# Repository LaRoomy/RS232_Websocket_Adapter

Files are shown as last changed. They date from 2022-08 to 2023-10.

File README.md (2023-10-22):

# RS232_Websocket_Adapter



This Project could be considered as the next-level development after my accomplishments with the apps for the serial data transmission to/from older EPL2 based machines. There were a few points which bothered me on my recent solutions: First thing is that the computer has to come to the machine, means there hast to be a (short) cable connection. What if I want to send data from the office? Second thing is the limitation to the windows platform. What if I want to use a mac or an android/ios-tablet or something. So this project accomplishes the following:
- Enable data exchange over RS232 interface (especially for EPL2 based machines)
- Exchange this data over a wireless connection in the local network
- Provides a platform independent front-end which can be accessed via browser

This repository provides all necessary data to build the WebSocket-Adapter.
- CAD data to create the [printed circuit board](CAD/Board)
- CAD data to create the [case](CAD/Case) for the adapter with a 3D printer
- The source code for the [backend/frontend](RS232WebSocketAdapter)

The front-end is accessible via browser from every device in the local network over the url "ncinterface.local".

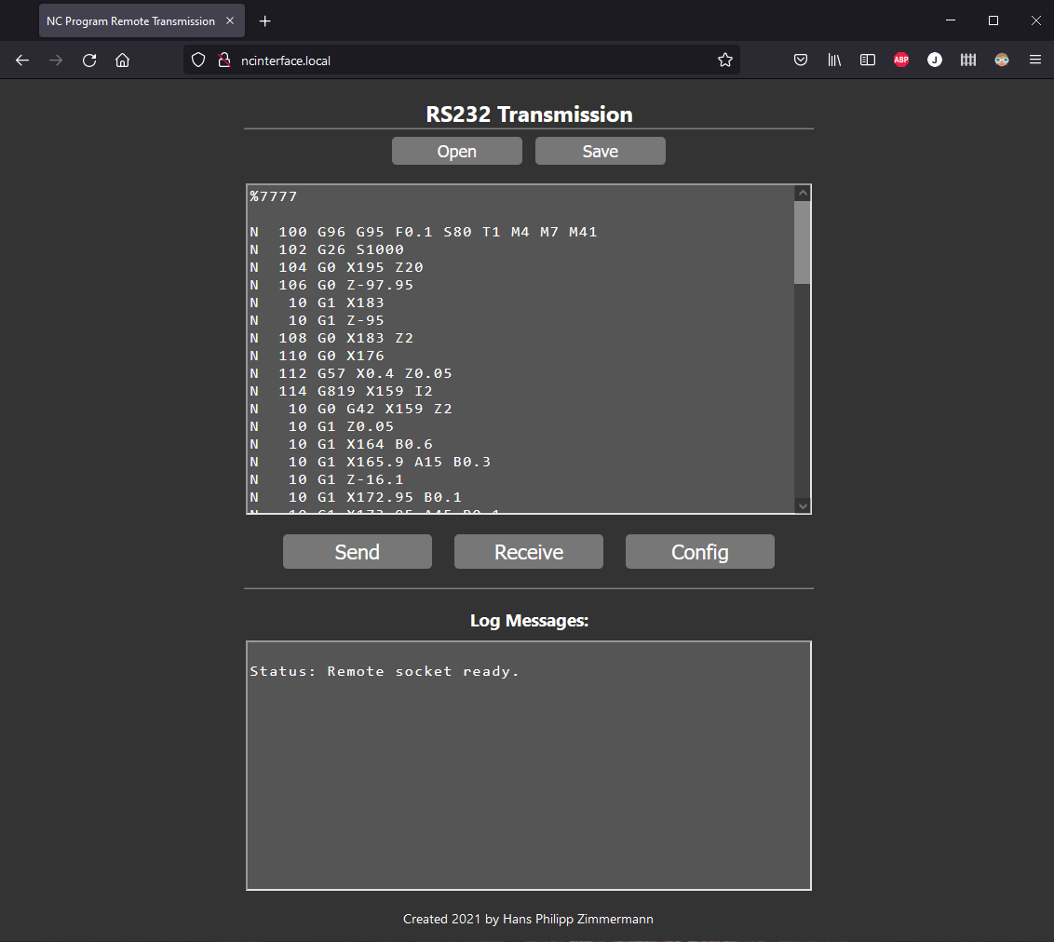
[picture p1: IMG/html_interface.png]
front-end view


### Special capabilities of the adapter
- The board contains a switch to select the RX/TX mode. The two lines can be crossed by this switch or used in line.
- The board also has pinheader bars. The level of these bars can be set directly out of the program and indiviually set for each of the hardware-handshake pins of the RS232 interface. This ensures the possibility to make the interface conform to every handshake needs of the machine.

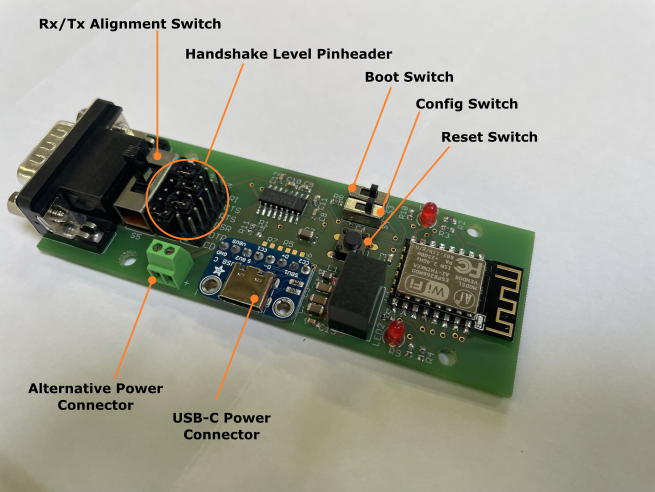
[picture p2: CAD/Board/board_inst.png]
board specifications


**NOTE:** _In this picture the config-switch is in the **normal execution** position and the boot-switch is in **program mode** position_

### How it works

The adapter logs in to the local network and advertises its local domain *ncinterface.local* via MDNS. It acts as an webserver. By entering the url *ncinterface.local* the interface website is loaded and remains connected by a websocket. The interface consists of the transmission page and the config page. The RS232 connection parameter can be set using the config page.

### How to configure the network

To set up the network credentials the serial connection of the adapter must be used. Connect the adapter to a pc via USB to Serial adapter. Make sure all jumper of the handshake-pinheader bars are removed. Otherwise it will not work properly. The config switch of the adapter must be set to the appropriate position. Now connect the power-source and the device will start in config mode. To configure the network every serial terminal program can be used. I recommend to use my free app [*EPL Exchange*](https://epl-exchange.blogspot.com/). The parameters of the config interface are:
- Baudrate: 9600
- Parity: None
- Databits: 8
- Stopbits: 1
- Handshake: None

To set up the SSID (network name): type in "ssid", to set up the password for the network: type in "password" and follow the prompt respectively. Typing in "?" shows instructions to use. To check if the connection works, put the config switch in the *normal execution* position and press reset. While trying to connect the red led blicks. If the device is connected to the network the blue led is on.

### How to get it ready to use

In many modern scenarios the handshake is ignored, known as RS232 3-wire interface, but machines running EPL2 needs specific levels on specific hardware handshake pins during transmission and some other pins must be set to GND. The following configuration worked for all machines I have to do with:

| Pin Name | Configuration |
| --- | --- |
| RI | GND |
| CTS | GND |
| RTS | OUT |
| DSR | Not connected |
| DTR | OUT |
| CD | GND |

When the jumper bridges on the pinheaders are connected. Make sure the config-switch is in *normal execution* position and the boot-switch is in *program mode* position. Set the Rx/Tx switch in the appropriate position and connect the adapter with the machine. Plug the power source in. If all is correct configured, the adapter shows the blue led indicating the successful connection with the network.

Now every device in the local network is able to access the adapters interface by opening the url **ncinterface.local**

#### Note:
- There are some problems with browsers. I recommend firefox, this works on all platforms. The known problems are:
   - Microsoft Edge does not support opening *.local* urls. Instead a internet search is being performed. The solution here is to add the url as a bookmark. Clicking this bookmark opens the interface.
   - On iOS, Safari has problems with the websocket because the app using this interface must have permission granted to use the local network. Safari does not  seem to have this capability at all, so it won't work. Other browsers on iOS, like firefox, are working. By opening the interface a dialog to request the permission to use the local network is displayed. This must be positive confirmed.
- The interface configuration which can be done on the config page is only for the transmission mode (when sending data via WLAN), **NOT** for the configuration interface of the adapter. The configuration interface parameter are always the same (printed earlier in this readme).

### Resources
- Printed Circuit Board resources can be found [here](CAD/Board)
- CAD files for the case are located [here](CAD/Case)
- The source-code for controller is [here](RS232WebSocketAdapter)
- A website with further information on the [EPL2 data-transmission](https://epl2-datatransmission.blogspot.com/2020/08/epl2-datenubertragung.html)
- Infos about the application [EPL-Exchange](https://epl-exchange.blogspot.com/) which could be used to configure the adapter

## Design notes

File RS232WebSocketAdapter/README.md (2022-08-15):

## RS232 WebSocket-Adapter Firmware project

This is the firmware for the WebSocket-Adapter.
- MCU: Espressif ESP8266
- Development Platform: [PlatformIO](https://platformio.org/)
- Framework: Arduino
- IDE: [Microsoft Visual Studio Code](https://platformio.org/platformio-ide)

---

### How to build
- Download [Visual Studio Code](https://platformio.org/platformio-ide)
- Install the PlatformIO IDE Extension
- Extensions for code management are also necessary. We need support for C/C++ and html/css/javascript
- Clone this Repository to your local machine
- Open the sub-folder *RS232WebSocketAdapter* of the Repository in VSCode. Or use the PlatformIO Extension and select *Open Project*. Anyway the opened folder must contain the *platformio.ini* file
- Click on the PlatformIO icon on the left pane to open the project tasks.
- Make sure to enter the boot mode of the device by switching the boot switch in the *boot mode* position and then press reset to enter boot mode
- Select *Build Filesystem Image* and when finished select *Upload Filesystem Image*
- Open the *root.h* file in the editor.

Here are two defines:
```C++
// if set, this enables some functions which are only intended for testing purposes
#define     EVALUATION_MODE

// if set, this initializes the eeprom persistent data, only intended for initial startup of the device
#define     INITIAL_MODE 
```
If the evaluation-mode define is set, the device outputs log messages on the serial interface. This is helpful while developing, but is not allowed if the device is used as intended since the serial interface is used to transmit data to the rs232 endpoint.

When first uploading the firmware to the device, the initial-mode define should be set to init the (pseudo)eeprom data segment with valid values. Otherwise the config parameter are loaded with invalid values. But if this is done, the define must be commented out and the firmware must be overridden with the new binary.

- Select *Build* in the project tasks list on the left
- When finished, select *Upload*
- If this was the first build, put the boot switch in *program mode* position and press reset. When the program was executed once on the device, put the device back in boot mode. Disable the initial-mode define value and click *Build* and *Upload* again.

### Sequence of the program
- On startup the device checks the configuration switch
- If it is set, the device enteres the configuration mode and the network credentials can be configured via serial interface
- Otherwise the device tries to connect to saved ssid/password combination
- If the connection succeeded, the device enteres data transmission mode and the interface can be accessed via *ncinterface.local* inside of the local network
- If the connection fails, the device enters the configuration mode

### Source Files
The MCU data consists of two elements: the firmware and the filesystem-image.

The filesystem image is used to store the files for the WebServer (html, css, js):
- **webSocket_nc_Transmission.html**  (front-end code for the transmission page of the interface)
- **webSocket_nc_Configuration.html**  (front-end code for the configuration page of the interface)
- **exStyles.css**  (provides the styles for the html pages)
- **exec_script.js**  (implements the back-end websocket functionality, and page behavior)

The C++ source files are used to generate the binary for the MCU:
- **root.h / root.cpp**  (implements the main functionality)
- **serial.h / serial.cpp**  (implements the serial interface communication)
- **stringtable.h**  (provides the strings for the user-interface)
- **main.cpp**  (entry-point of the WebSocket-Adapter firmware):

```C++
#include "root.h"

// create root instance
RootComponent rootC;

// valid access to root instance from all locations
RootComponent* getRootClass(){
  return &rootC;
}

void setup(){
  // initialize component
  rootC.init();
}

void loop(){
  // run
  rootC.onLoop();
}
```
As you can see, the whole functionality is coverd by the instance of the RootComponent object.

---

### Note:
With the pinheaders on the board it is possible to set each hardware handshake pin to a specific level (HIGH/LOW). Place a jumper bridge either to the GND pinheader or to the OUT pinheader. The OUT pinheader can be controlled from the firmware to customize the levels of the pin on a specific operation.

**But when programming or configuring the device, all jumper must be removed to ensure a reliable operation.**

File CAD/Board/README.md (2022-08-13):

## RS232 WebSocket-Adapter Board

This is the CAD data section for the printed circuit board. The board file is production-ready.

Schematic:

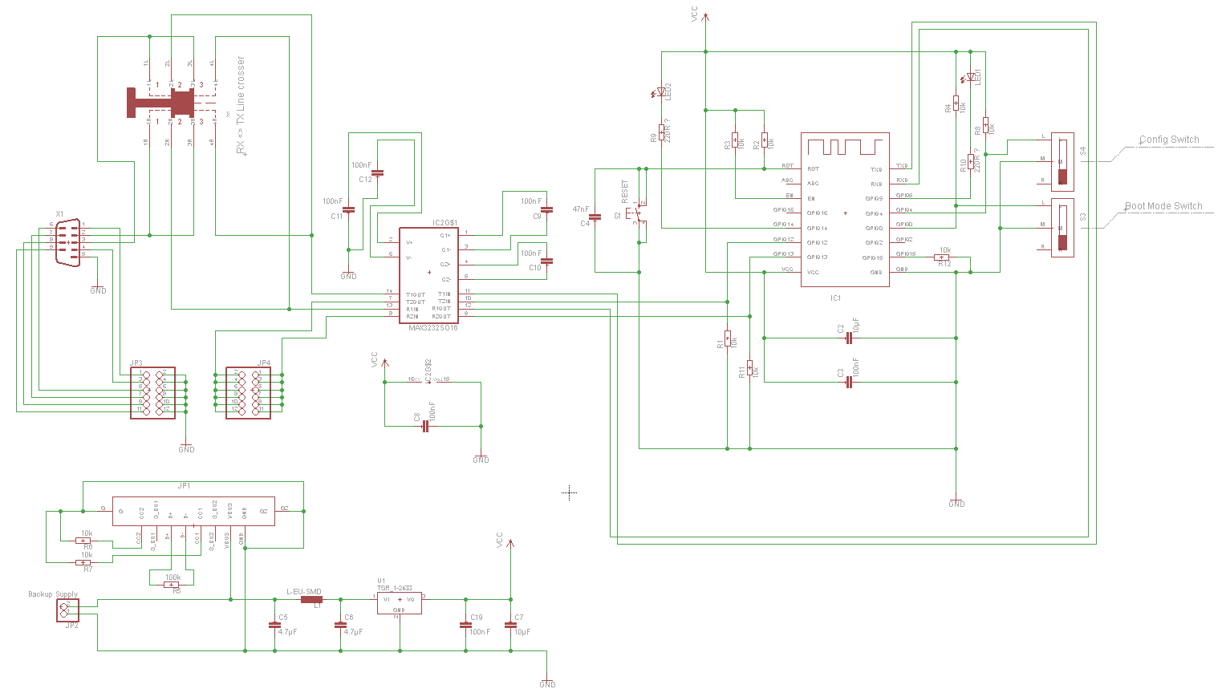
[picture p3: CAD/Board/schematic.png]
RS232 Websocket-Adapter board schematic


---

Board:

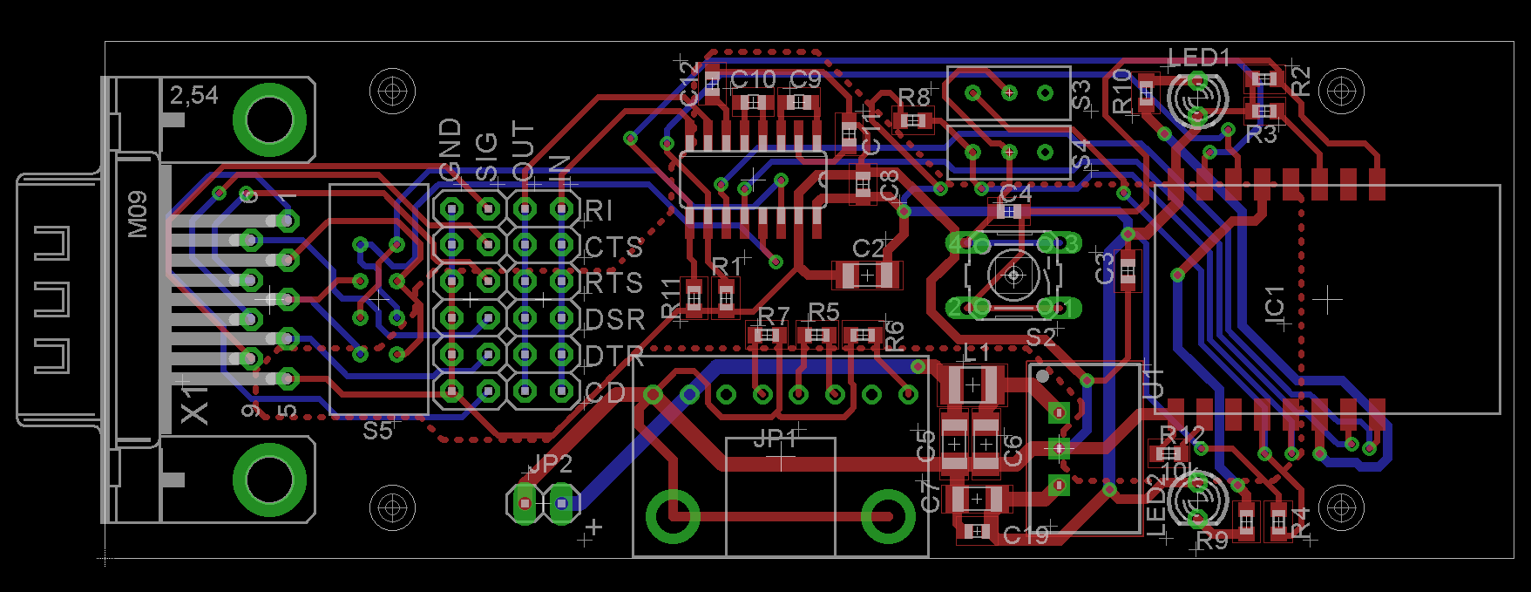
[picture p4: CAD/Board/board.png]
RS232 Websocket-Adapter board


---

Final assembly:

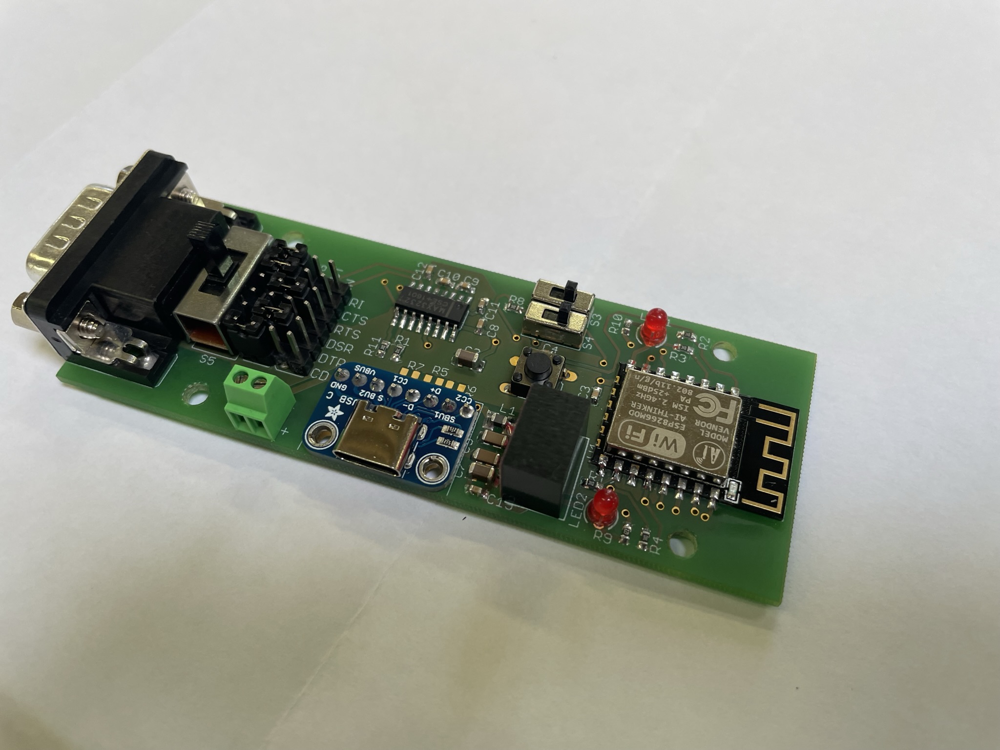
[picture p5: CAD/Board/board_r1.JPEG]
 

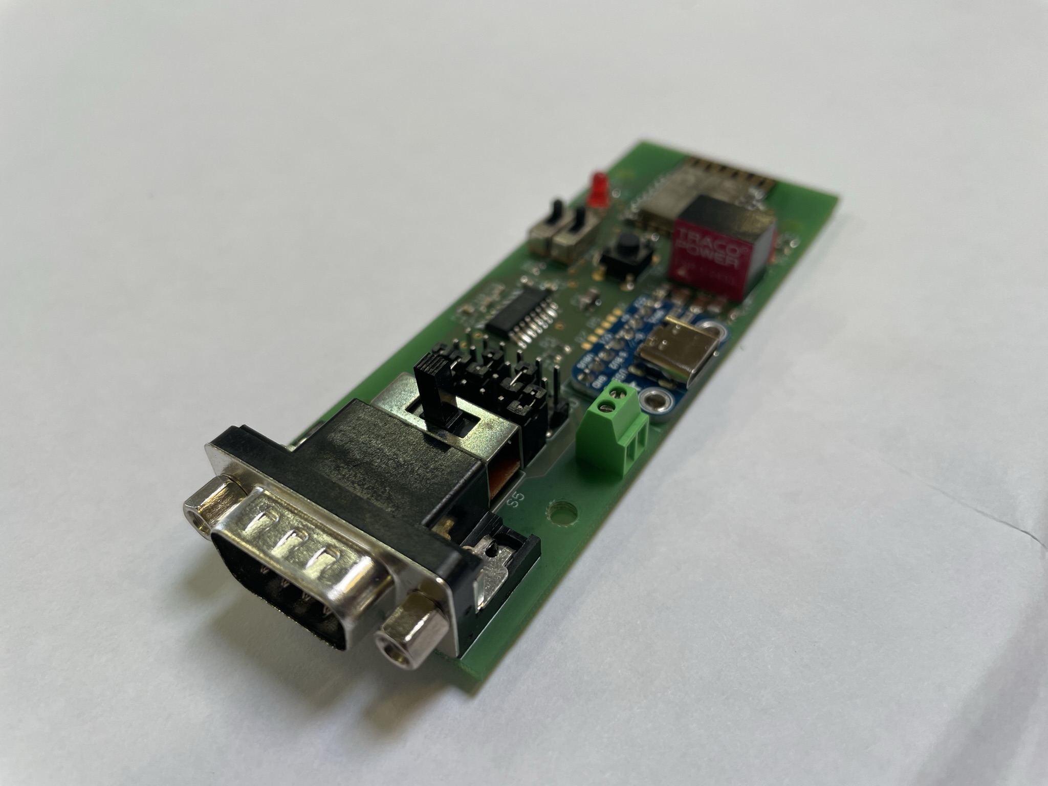
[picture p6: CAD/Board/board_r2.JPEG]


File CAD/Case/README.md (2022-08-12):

## RS232 WebSocket-Adapter Case CAD Files

The case of the adapter comes in two parts. The top and the bottom case. Here are both in different 3D file formats.

Top case                                       | Bottom case
:---------------------------------------------:|:----------------------------------------------------:
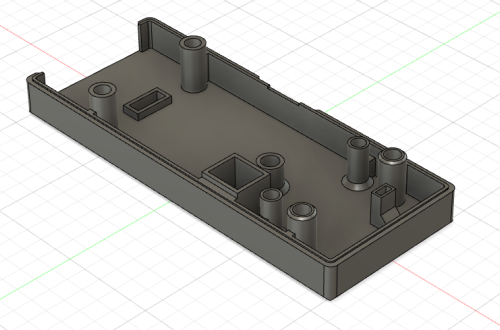
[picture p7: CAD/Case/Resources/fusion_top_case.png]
The top case
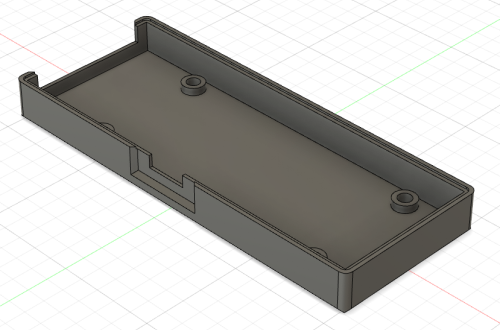
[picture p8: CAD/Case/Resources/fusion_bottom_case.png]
The bottom case
 | 

Printed parts with thread-insets:

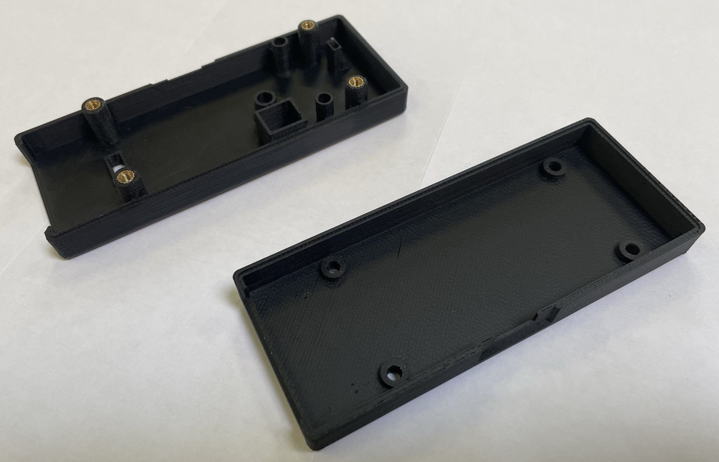
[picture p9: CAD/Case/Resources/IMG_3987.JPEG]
Printed parts


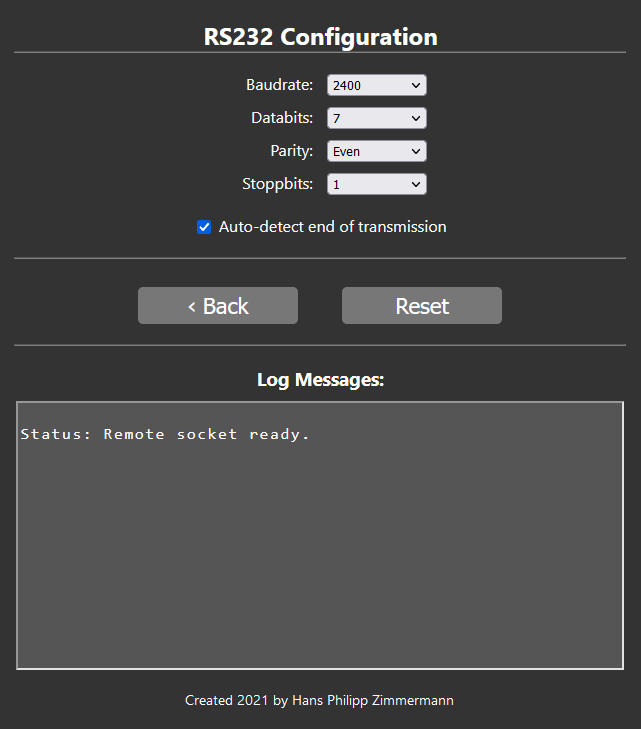
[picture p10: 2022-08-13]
IMG/html_config.png

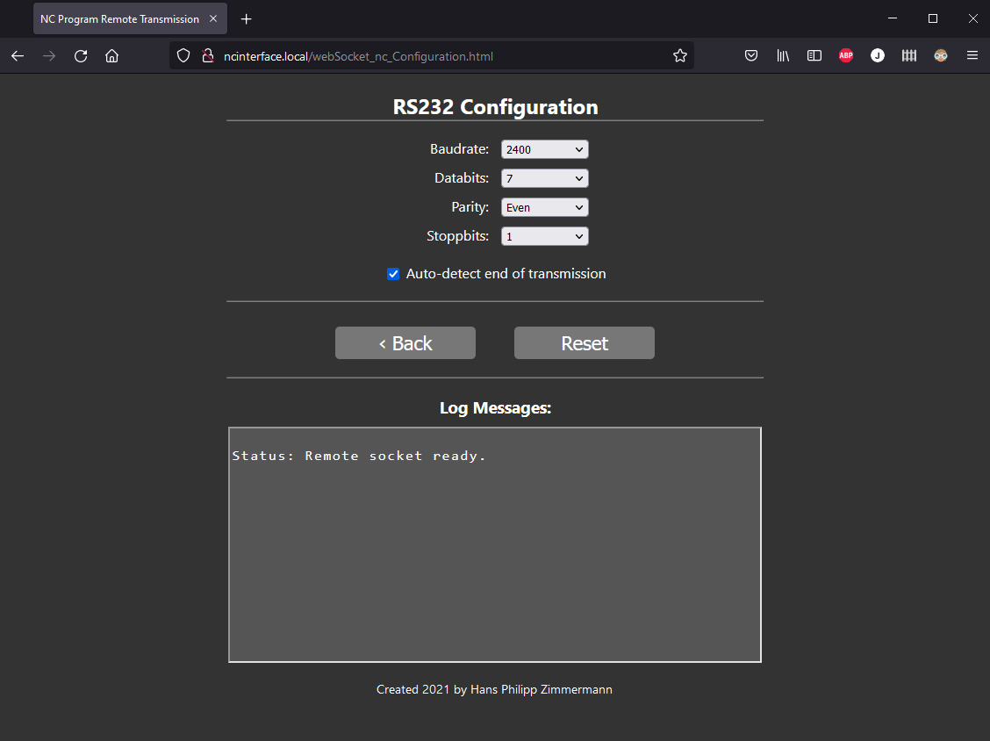
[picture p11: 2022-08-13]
IMG/html_config2.png

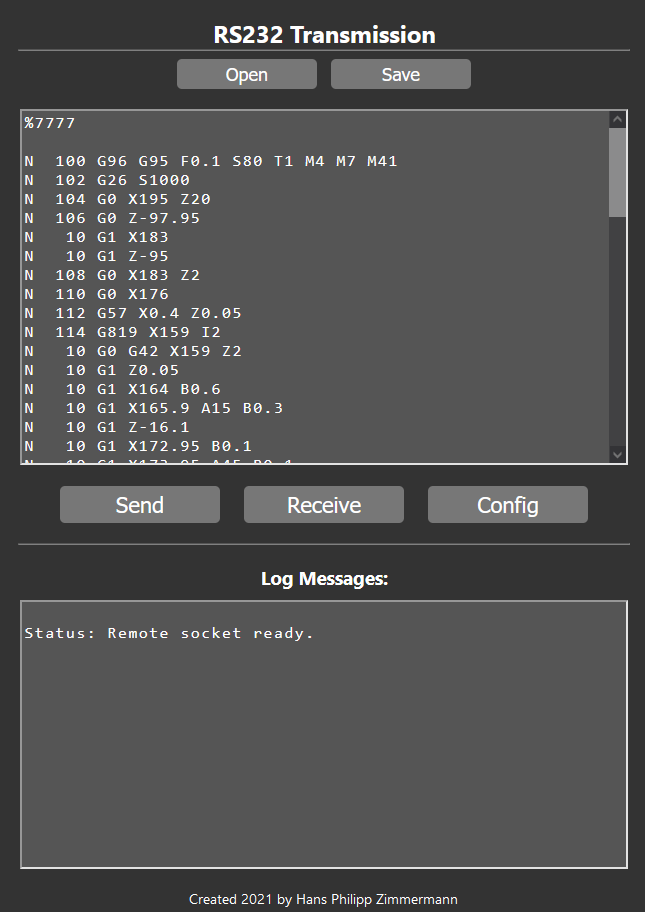
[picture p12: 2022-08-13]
IMG/html_interface1.png

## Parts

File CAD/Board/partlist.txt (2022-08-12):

Partlist

Exported from RS232_Websocket.brd at 27.11.2021 17:50:55

Assembly variant: 

Part     Value          Package        Library 

C2       10µF           C1206          resistor
C3       100nF          C0603          resistor 
C4       47nF           C0603          resistor 
C5       4.7µF          C1206          resistor 
C6       4.7µF          C1206          resistor
C7       10µF           C1206          resistor 
C8       100nF          C0603          resistor 
C9       100nF          C0603          resistor 
C10      100nF          C0603          resistor 
C11      100nF          C0603          resistor 
C12      100nF          C0603          resistor  
C19      100nF          C0603          resistor   
IC1      ESP8266MOD_AI  ESP8266MOD     ESP8266MOD_AiThinker
ICM      MAX3232SO16    SO16           maxim-7a
JP1      USB-C_BREAKOUT USB-C_BREAKOUT USB-C Breakout Ada
JP2      Backup Supply  1X02           pinhead 
JP3                     2X06           pinhead
JP4                     2X06           pinhead 
L1       L-EU-SMD       R1210          resistor 
LED1                    LED3MM         led   
LED2                    LED3MM         led  
R1       10k            R0603          resistor 
R2       10k            R0603          resistor  
R3       10k            R0603          resistor 
R4       10k            R0603          resistor  
R5       100k           R0603          resistor 
R6       10k            R0603          resistor  
R7       10k            R0603          resistor  
R8       10k            R0603          resistor 
R9       220R           R0603          resistor 
R10      220R           R0603          resistor 
R11      10k            R0603          resistor 
R12      10k            R0603          resistor 
S2                      B3F-10XX       switch-omron 
S3       3POS_SWITCH    2POS_SWITCH    3-Step-Switch
S4       3POS_SWITCH    2POS_SWITCH    3-Step-Switch 
S5       3X2_SWITCH     3X2_SWITCH     Switches 
U1       TSR_1-2433     TSR-1          _traco_tsr-1 
X1                      M09HP          con-subd

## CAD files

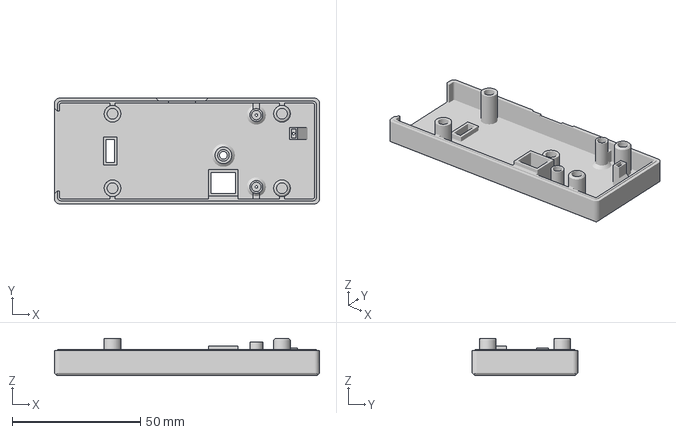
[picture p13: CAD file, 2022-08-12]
CAD/Case/RS232 Socket Upper Case.3mf
103.2 x 41.2 x 14.5 mm

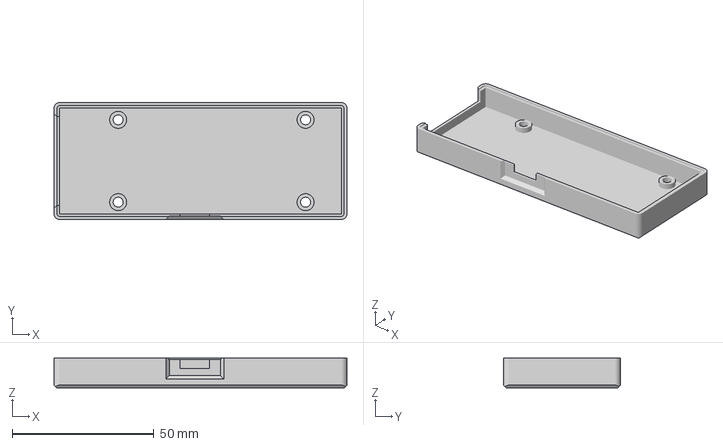
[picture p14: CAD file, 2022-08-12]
CAD/Case/RS232 Socket Lower Case.3mf
103.2 x 41.2 x 10.5 mm

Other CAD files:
CAD/Case/RS232 Socket Lower Case.stl
CAD/Case/RS232 Socket Upper Case.stl

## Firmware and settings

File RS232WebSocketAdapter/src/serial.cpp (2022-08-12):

#include "serial.h"
#include <limits.h>

unsigned int ticks = 0;


void SerialTransmissionHandler::config(unsigned long baudrate,DATABITS db, PARITY p, STOPPBITS sb){

    this->baud = baudrate;
    
    if(p == PARITY::NONE){
        if(sb == STOPPBITS::ONE){
            switch (db)
            {
            case DATABITS::FIVE:
                this->conf = SERIAL_5N1;
                break;
            case DATABITS::SIX:
                this->conf = SERIAL_6N1;
                break;
            case DATABITS::SEVEN:
                this->conf = SERIAL_7N1;
                break;
            case DATABITS::EIGHT:
                this->conf = SERIAL_8N1;
                break;            
            default:
                break;
            }
        }
        else if(sb == STOPPBITS::TWO){
            switch (db)
            {
            case DATABITS::FIVE:
                this->conf = SERIAL_5N2;
                break;
            case DATABITS::SIX:
                this->conf = SERIAL_6N2;
                break;
            case DATABITS::SEVEN:
                this->conf = SERIAL_7N2;
                break;
            case DATABITS::EIGHT:
                this->conf = SERIAL_8N2;
                break;            
            default:
                break;
            }
        }
    }
    else if(p == PARITY::EVEN){
        if(sb == STOPPBITS::ONE){
            switch (db)
            {
            case DATABITS::FIVE:
                this->conf = SERIAL_5E1;
                break;
            case DATABITS::SIX:
                this->conf = SERIAL_6E1;
                break;
            case DATABITS::SEVEN:
                this->conf = SERIAL_7E1;
                break;
            case DATABITS::EIGHT:
                this->conf = SERIAL_8E1;
                break;            
            default:
                break;
            }
        }
        else if(sb == STOPPBITS::TWO){
            switch (db)
            {
            case DATABITS::FIVE:
                this->conf = SERIAL_5E2;
                break;
            case DATABITS::SIX:
                this->conf = SERIAL_6E2;
                break;
            case DATABITS::SEVEN:
                this->conf = SERIAL_7E2;
                break;
            case DATABITS::EIGHT:
                this->conf = SERIAL_8E2;
                break;            
            default:
                break;
            }
        }
    }
    else if(p == PARITY::ODD){
        if(sb == STOPPBITS::ONE){
            switch (db)
            {
            case DATABITS::FIVE:
                this->conf = SERIAL_5O1;
                break;
            case DATABITS::SIX:
                this->conf = SERIAL_6O1;
                break;
            case DATABITS::SEVEN:
                this->conf = SERIAL_7O1;
                break;
            case DATABITS::EIGHT:
                this->conf = SERIAL_8O1;
                break;            
            default:
                break;
            }
        }
        else if(sb == STOPPBITS::TWO){
            switch (db)
            {
            case DATABITS::FIVE:
                this->conf = SERIAL_5O2;
                break;
            case DATABITS::SIX:
                this->conf = SERIAL_6O2;
                break;
            case DATABITS::SEVEN:
                this->conf = SERIAL_7O2;
                break;
            case DATABITS::EIGHT:
                this->conf = SERIAL_8O2;
                break;            
            default:
                break;
            }
        }
    }   
}

void SerialTransmissionHandler::sendData(){
    if(this->currentTransmission != TRANSMISSION_TYPE::NONE){
        if(this->eventHandler != nullptr){
            this->eventHandler->onError(TRANSMISSION_ERROR::TRANSMISSION_ALREADY_IN_PROGRESS);
        }
    }
    else {
        // make sure to add a linefeed delimiter on the end of the buffer
        //      -> otherwise the last line will not be recognized
        this->transmissionData += "\n\0";

        this->transmissionIndex = 0;
        this->currentTransmission = TRANSMISSION_TYPE::SEND;

        /*
            Here the GPIO12 pin is set to low level, this pin is connceted to the T2_IN pin of the
            Max3232 IC. Setting this pin to low has the inverting effect on the output pin T2_OUT of the Max3232 which is
            set high on RS232 level. The output pin is connected to the OUT-Pinheader row of the jumper area, so setting a
            jumper-bridge from the OUT header to the single signal pin sets this hardware handshake pin to high level before
            the sending process is started.
        */
        digitalWrite(HANDSHAKE_SIGNAL_PIN, LOW);

        Serial.begin(this->baud, this->conf);
    }
}

void SerialTransmissionHandler::sendData(String data){
    if(this->currentTransmission != TRANSMISSION_TYPE::NONE){
        if(this->eventHandler != nullptr){
            this->eventHandler->onError(TRANSMISSION_ERROR::TRANSMISSION_ALREADY_IN_PROGRESS);
        }
    }
    else {
        this->transmissionData = data;

        // make sure to add a linefeed delimiter on the end of the buffer
        //      -> otherwise the last line will not be recognized
        this->transmissionData += "\n\0";

        this->transmissionIndex = 0;
        this->currentTransmission = TRANSMISSION_TYPE::SEND;

        /*
            Here the GPIO12 pin is set to low level, this pin is connceted to the T2_IN pin of the
            Max3232 IC. Setting this pin to low has the inverting effect on the output pin T2_OUT of the Max3232 which is
            set high on RS232 level. The output pin is connected to the OUT-Pinheader row of the jumper area, so setting a
            jumper-bridge from the OUT header to the single signal pin sets this hardware handshake pin to high level before
            the sending process is started.
        */
        digitalWrite(HANDSHAKE_SIGNAL_PIN, LOW);

        Serial.begin(this->baud, this->conf);
    }
}

void SerialTransmissionHandler::terminal_sendData(String data){
    Serial.write(data.c_str());
    Serial.flush();
}
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

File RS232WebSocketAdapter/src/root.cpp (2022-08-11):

#include "root.h"

void RootComponent::init(){

    uint8_t ledState = 1;

#ifdef  EVALUATION_MODE
    // Serial port for testing purposes
    Serial.begin(115200);
#endif

    LittleFS.begin();
    EEPROM.begin(EE_PROM_SIZE);

#ifdef INITIAL_MODE
    // necessary for first initialization!
    EEPROM.write(EE_BAUD_ADDR, 255);
    EEPROM.write(EE_DATAB_ADDR, 255);
    EEPROM.write(EE_PARITY_ADDR, 255);
    EEPROM.write(EE_STOPPB_ADDR, 255);
    EEPROM.write(EE_AD_EOT_ADDR, 255);
    EEPROM.write(EE_WLAN_PASSWRD_LENGTH_ADDR, 0);
    EEPROM.write(EE_WLAN_SSID_LENGTH_ADDR, 0);
    EEPROM.commit();
#endif

    this->loadPersistentData();

    // subscribe serial transmission callback
    this->sHandler += this;
    this->sHandler.setAutoDetectEndOfTransmission(this->autoDetectEOT);

    pinMode(LED_BUILTIN, OUTPUT);
    digitalWrite(LED_BUILTIN, HIGH);// hint: low == led on

    pinMode(D2, INPUT);
    pinMode(D5, OUTPUT);
    pinMode(HANDSHAKE_SIGNAL_PIN, OUTPUT);
    digitalWrite(D5, ledState);// hint: low == led on
    digitalWrite(HANDSHAKE_SIGNAL_PIN, HIGH);

    // tx config
    pinMode(D10, OUTPUT);
    digitalWrite(D10, HIGH);
  
    // Connect to Wi-Fi (if credentials are set and the config-switch is NOT on)
    if((this->network_ssid.length() > 0) && (this->network_password.length() > 0) && (digitalRead(D2) == HIGH)){

#ifdef  EVALUATION_MODE
      Serial.println(this->network_ssid.c_str());
#endif

      // connect
      WiFi.begin(
        this->network_ssid.c_str(),
        this->network_password.c_str()
        );

      // wait for connection
      while (WiFi.status() != WL_CONNECTED) {
        delay(500);

#ifdef  EVALUATION_MODE        
        Serial.println("Connecting to WiFi..");
#endif

        ledState = !ledState;
        digitalWrite(D5, ledState);

        // check config switch
        if(digitalRead(D2) == LOW){
          ESP.restart();
        }
      }
          
#ifdef  EVALUATION_MODE          
      // Print ESP Local IP Address
      Serial.println(WiFi.localIP());
#endif

      // set led to on, to indicate connection status: connected
      digitalWrite(LED_BUILTIN, LOW);

      // activate multicast dns
      MDNS.begin("ncinterface");

#ifdef  EVALUATION_MODE        
      if(!MDNS.begin("ncinterface")){
        Serial.println("Error setting up MDNS!");
      }
      else {
        Serial.println("MDNS started.");
      }
#endif
      
      // init websocket
      initWebSocket();

      // Route for root / web page
      this->server.on("/", HTTP_GET, [](AsyncWebServerRequest *request){
          request->send(LittleFS, "/webSocket_nc_Transmission.html", String(), false);
      });

      // Route for config / web page
      this->server.on("/webSocket_nc_Configuration.html", HTTP_GET, [](AsyncWebServerRequest *request){
          request->send(LittleFS, "/webSocket_nc_Configuration.html", String(), false);
      });

      // Route for javascript file
      this->server.on("/exec_script.js", HTTP_GET, [](AsyncWebServerRequest *request){
          request->send(LittleFS, "/exec_script.js", "text/javascript");
      });

      // Route for css file
      this->server.on("/ex_styles.css", HTTP_GET, [](AsyncWebServerRequest *request){
          request->send(LittleFS, "/ex_styles.css", "text/css");
      });

      // start server
      this->server.begin();

      // disable config-led for further usage
      digitalWrite(D5, HIGH);

#ifdef  EVALUATION_MODE
      // stop serial
      Serial.flush();
      Serial.end();
#endif

    }
    else {

#ifdef  EVALUATION_MODE      
      Serial.println("No network credentials. Only config mode available.");
      // stop serial
      Serial.flush();
      Serial.end();
#endif      

      // set config mode
      this->mode = DEVICEMODE::CONFIGMODE;

      // indicate entering the config-mode by led
      digitalWrite(D5, LOW);

      // config and start serial interface
      //this->sHandler.config(this->scBaudRate, this->scDatabits, this->scParity, this->scStoppbits);
      this->sHandler.config(9600, DATABITS::EIGHT, PARITY::NONE, STOPPBITS::ONE);
      this->sHandler.startTerminal();
    }
}

void RootComponent::onLoop(){

    if(this->mode == DEVICEMODE::SOCKETMODE){
      // websocket
      ws.cleanupClients();
      // mdns
      MDNS.update();
      // handle serial transmission
      sHandler.processSerialTransmission();

      // check system switch for config-mode
      if(digitalRead(D2) == LOW){
        // enter config-mode
        this->enterConfigMode();
      }

      // indicate connection status with system led
      if(WiFi.isConnected()){
        digitalWrite(LED_BUILTIN, LOW);
      }
      else {
        // wifi is disconnected -> try to re-connect
        digitalWrite(LED_BUILTIN, HIGH);
        this->reConnect();
      }
    }
    else {
      // this is the config mode
      this->sHandler.processTerminalTransmissions();
      // check system switch to exit config-mode
      if(digitalRead(D2) == HIGH){
        // leave the config mode
        this->leaveConfigMode();
      }
    }
}

void RootComponent::onSendComplete(unsigned int bytesTransferred){
    String message(I_MSG_SEND_OPERATION_COMPLETE);
    message += bytesTransferred;
    this->notifyUser(message);
}

void RootComponent::onReceptionComplete(const String& buffer, size_t size){
    if(this->mode == DEVICEMODE::CONFIGMODE){
      this->onHandleTerminalCommunication(buffer);
    }
    else {
      // notify user
      String message(I_MSG_RECEIVE_OPERATION_COMPLETE);
      message += size;
      this->notifyUser(message);
      // send buffer to websocket
      this->ws.textAll("_Csrt");
      String setter("_Crrr");
      setter += buffer;
      this->ws.textAll(setter);
    }
}

void RootComponent::onReceptionStarted(){
    ws.textAll("_CsrsE");
}

void RootComponent::onError(TRANSMISSION_ERROR error){
  switch(error){
    case TRANSMISSION_ERROR::TRANSMISSION_ALREADY_IN_PROGRESS:
      this->notifyUser(E_MSG_TRANSMISSION_ALREADY_IN_PROGRESS);
      break;
    case TRANSMISSION_ERROR::INVALID_SEND_IS_ACTIVE:
      this->notifyUser(E_MSG_INVALID_SEND_IS_ACTIVE);
      break;
    default:
      break;
  }
}
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
